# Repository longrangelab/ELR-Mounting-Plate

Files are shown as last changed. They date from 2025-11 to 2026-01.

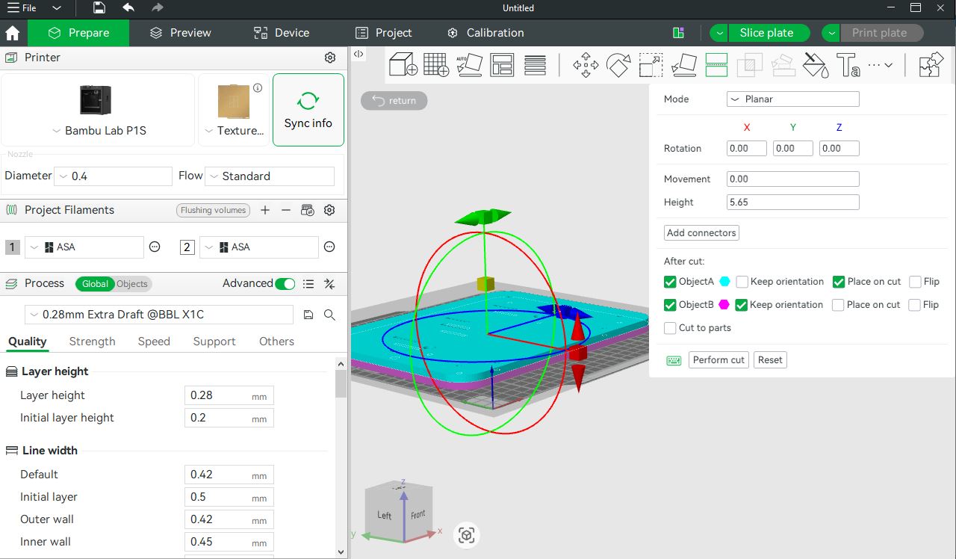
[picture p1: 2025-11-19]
Assets/2nd Cut.JPG

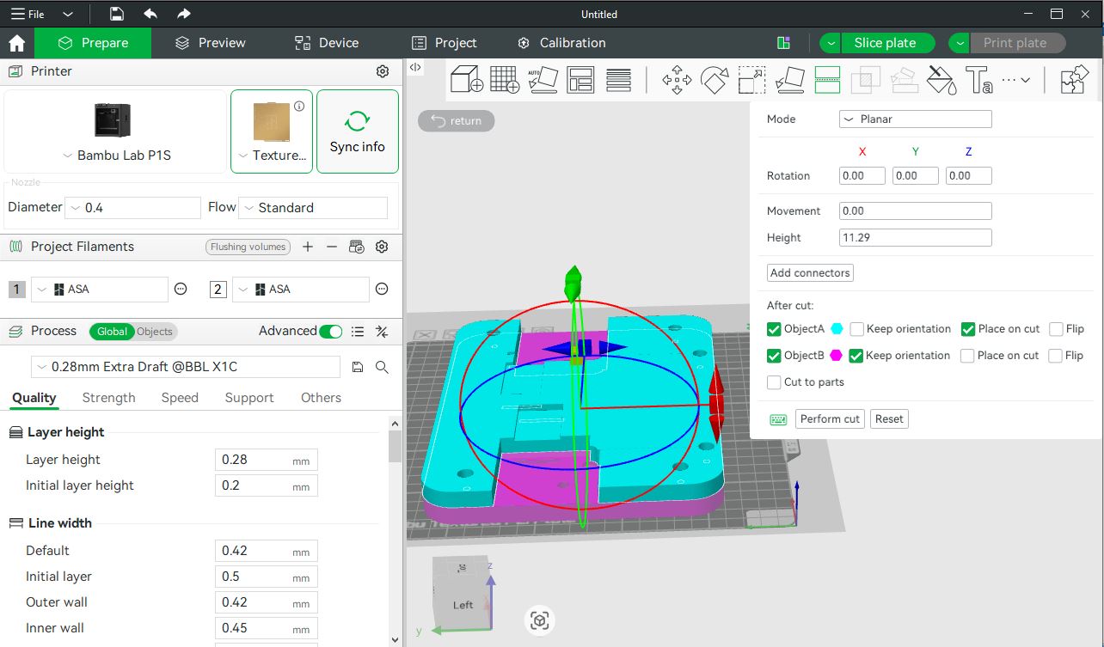
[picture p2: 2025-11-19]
Assets/1st cut.JPG

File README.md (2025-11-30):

# ELR-Mounting-Plate
A rugged, mounting solution for securely attaching electronic hit indicators to steel targets in extreme long-range (ELR) shooting setups. Designed for durability, repeatability, and easy integration with common target systems.
## Open Source Collaboration
The ELR Mounting Plate is fully open source, designed to be shared, modified, and improved by the shooting and maker community. While the current design includes brackets for the Caldwell Flash Bang and MagnetoSpeed T1000, the system is meant to be modular. I encourage contributors to design and submit new brackets for other hit indicators or accessories. By working together, we can expand the versatility of this mounting system and make it a universal solution for ELR shooters everywhere. This is a link to the ONShape document I have been working with:

- https://cad.onshape.com/documents/a04b2efc3583e73eb0067b3f/w/00cdbc6ac526f38cc4cbc277/e/5109c6cf2e963c5b981c8ac2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
Feel free to use it how you see fit :)
IMG_20251123_082742701_HDR
60 fps 0![Back On shape](https://github.com/user-attachments/assets/3fdb3622-1bf8-4e5c-a6eb-2b6bc96cb5c7) 0_00_09_03 Still001

# Current Features/Capabilities
- 🔧 **Hybrid Mounting System**  
  Combines a large Velcro surface with two neodymium magnets for constant pressure against the steel plate.
  
- 🛡️ **Durable Materials**  
  - **ASA plastic**: UV and impact resistant, ideal for outdoor use.  
  - **TPU rubber**: Provides shock absorption and prevents shattering under repeated impacts.  

- 🎯 **Adaptable Design**  
  Compatible with multiple hit indicators:
  - Coriolis Hit Indicator (future project to be completed)
  - Caldwell Flash Bang  
  - MagnetoSpeed T1000  
  - Can be adapted to virtually any hit indicator with future iteration
# To build the ELR Mounting Plate, you will need the following components:

| Qty | Item | Description | Link |
|-----|---|---|---|
| 2 | Neodymium Magnets | 180 lb pull force, heavy-duty magnets for mounting pressure | [Amazon Product Page](https://www.amazon.com/MUTUACTOR-Neodymium-Magnets-Anti-Broken-Equipments/dp/B07JKWCVTX) |
| 4 | M4 Screws (20mm)  | Standard metric screws for securing ASA and TPU layers | — |
| 2 | M4 Screws (25mm)  | Longer screws for reinforced bracket mounting | — |
| 2 | M4 Screws (30mm)  | Extra-long screws for thicker assemblies | — |
| 26  | M4 Washers | Flat washers to distribute load and prevent damage | — |
| 10  | M4 Lock Washers | Locking washers to resist loosening under vibration/impact | — |
| 10  | M4 Nuts | Standard nuts for fastening bolts | — |
| 2 | Velcro Adhesive Dots | 1.5” round industrial-strength adhesive fasteners for mounting | [Amazon Product Page](https://www.amazon.com/pson-Adhesive-Fasteners-Mounting-Industrial/dp/B0F4DZC5RM) |
| 2 | Velcro Pad (6x4”)  | Waterproof double-sided adhesive pad for larger mounting surface | [Amazon Product Page](https://www.amazon.com/Upgrade-Adhesive-Double-Side-Fastener-Waterproof/dp/B07D38TNF9) |
| 1 | Velcro Strap (1/2” wide) | Strap for securing Magneto Speed T1000 hit indicator | [Amazon Product Page](https://www.amazon.com/dp/B0CH8K8VWC) |
| 1 | Support Bar | Tool for safely removing the mounting plate from steel targets | [Amazon Product Page](https://www.amazon.com/dp/B0DYF8F2RN) |
| 1 | TPU 95 Filament | Flexible filament for impact-absorbing core | — |
| 1 | ASA Filament | UV and impact-resistant filament for outer plates | — |

# Step 1: Printing the Plate
- Start by downloading the ELR Mounting PLate STL in the stl folder. The orientation of the plate is pictured below. This requires no support.
- full plate before splitting
- Next, we'll split the plate into 3 different layers: Two layers of ASA on the outside with a layer of TPU sandwiched in the middle. 
- The first cut will be performed horizontally with a depth of approximately 10.37 mm. It will be printed with ASA. 
- 1st cut
- 1st Print ASA

- The next cut will split the remainder of the plate exactly in half, leaving a thickness of about 5.76 mm for the remaining two plates. 
- The opposite outside layer will also be printed with ASA
- 2nd Print ASA

- The third print will be with TPU 95
- 3rd Print TPU95

## Printer Filament Settings

The ELR Mounting Plate uses a **multi-material print** combining ASA for rigidity and TPU95 for impact absorption. Below are the recommended slicer settings for each material:

### ASA (Outer Plates)
| Setting | Value |
|---|---|
| Infill Percentage  | 30% |
| Infill Pattern | Gyroid |
| Wall Passes | 5 |
| Bottom Shell Layers| 5 |
| Top Shell Layers | 5 |

**Notes:**  
- ASA provides UV resistance and high impact strength, making it ideal for outdoor shooting environments.  
- Higher wall count and bottom layers ensure structural rigidity around magnet mounts and screw holes.  
- Gyroid infill balances strength with weight reduction.  

---

### TPU95 (Inner Core)
| Setting | Value |
|---|---|
| Infill Percentage  | 10% |
| Infill Pattern | Gyroid |
| Wall Passes | 3 |
| Bottom Shell Layers| 3 |
| Top Shell Layers | 3 |

**Notes:**  
- TPU95 acts as a shock absorber, preventing cracks and distributing impact forces.  
- Lower infill keeps the core flexible while still providing support.  
- Gyroid infill maintains elasticity and impact resistance.  

---

### Why These Settings?
- **ASA + TPU95 Hybrid:** The rigid ASA shell protects against environmental stress, while the TPU95 core absorbs repeated impacts.  
- **Gyroid Infill:** Provides isotropic strength and flexibility, superior to grid or honeycomb for impact-heavy applications.  
- **Wall Passes & Shell Layers:** Extra walls in ASA prevent shattering, while fewer walls in TPU maintain flexibility.
# Assembly
First, gather all three layers of the mounting plate and align them so that all holes line up. From the steel side view of the plate, place washers in all of the holes, minus the holes intended for the magnets. Place the appropriate size bolt in each of the holes according to the hardware schedule below:
Bolt Layout

Once all of the bolts are in, turn the plate around and place washers, lock washers, and nuts on each of the bolts except for the 4 bolts intended for the hit indicator bracket. 

Next, install the two magnets. Depending on how far you want the magnets to stick out past the plate, you can print TPU spacers that I've included in the STL folder and put this spacer behind the magnet. I would also
recommend using washers on the front side of the plate because this is likely a failure point. The washer will help distribute the large force over a larger footprint. 
Rubber Spacer

After the magnets are installed, stack 3 or 4 washers on each of the 30 mm long bolts to build up a base for the metal joiner bar. Place the joiner bar over the two 30 mm bolts and place a washer, locking washer, and nuts over both bolts. 

# Applying Adhesive Strips
Finally, it's time to apply the adhesive velcro to the back of the plate. Feel free to experiment with different brands of velcro adhesive. If you would like to have access to the ELR Mounting plate's screws, then I would recommend printing out the velcro stencil that I have included in the STL folder. 
Stencil for velcro

Using this stencil will allow you to cut out holes for screws in case you want to take the plate apart, or take the bracket off. 

Drawing holes out
Finished

## Hit indicator brackets

- After all of these steps are completed, you are done building the ELR Mounting Plate. All you have to do now is print the appropriate mounting bracket (Located in the STL folder. Print either the Magneto Speed T1000 or the Caldwell Top and Bottom brackets) depending on which hit indicator you have. You'll then slide the bracket over the 4 remaining bolts and lock the bracket down with locking washers and nuts. 

Fully completed unit

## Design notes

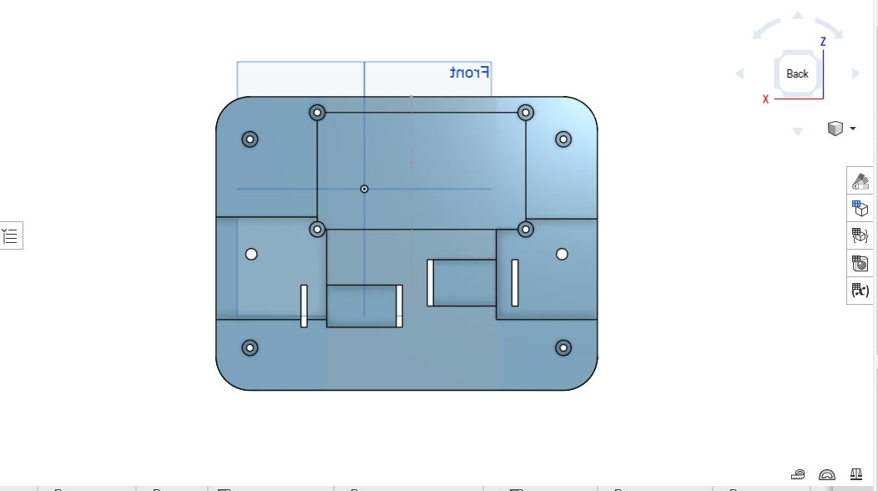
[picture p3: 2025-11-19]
Assets/Back On shape.JPG

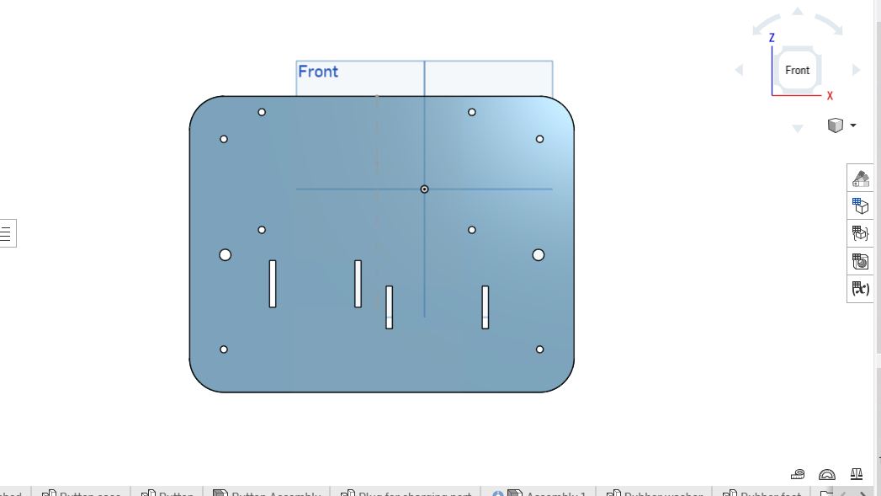
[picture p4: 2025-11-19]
Assets/Front On Shape.JPG

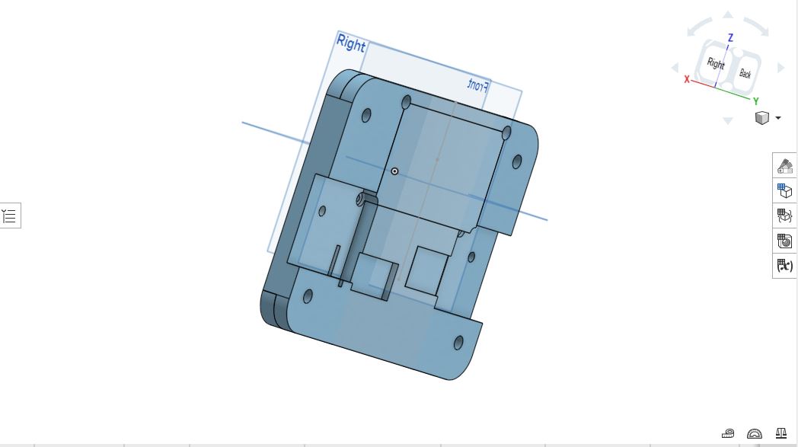
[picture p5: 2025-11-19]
Assets/3d view.JPG

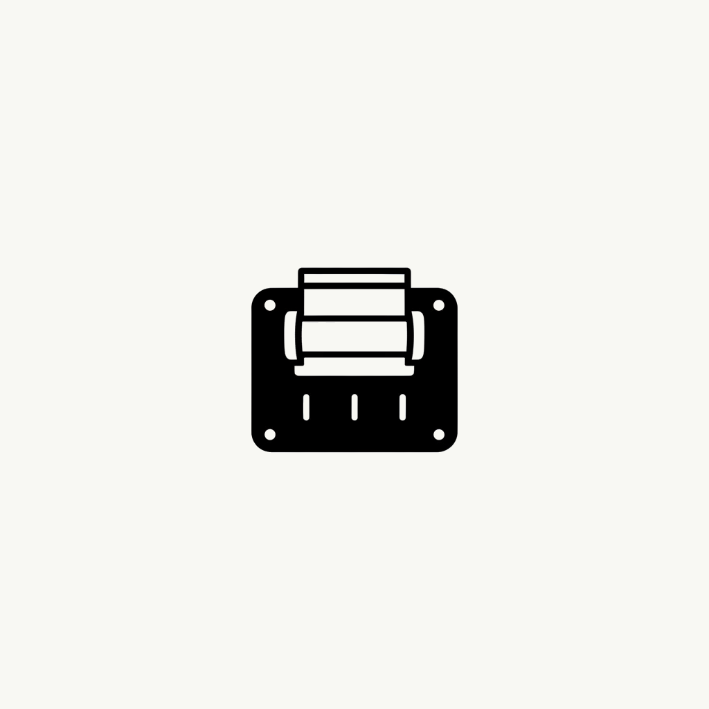
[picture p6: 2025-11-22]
Assets/ELR Mounting plate corrected.png

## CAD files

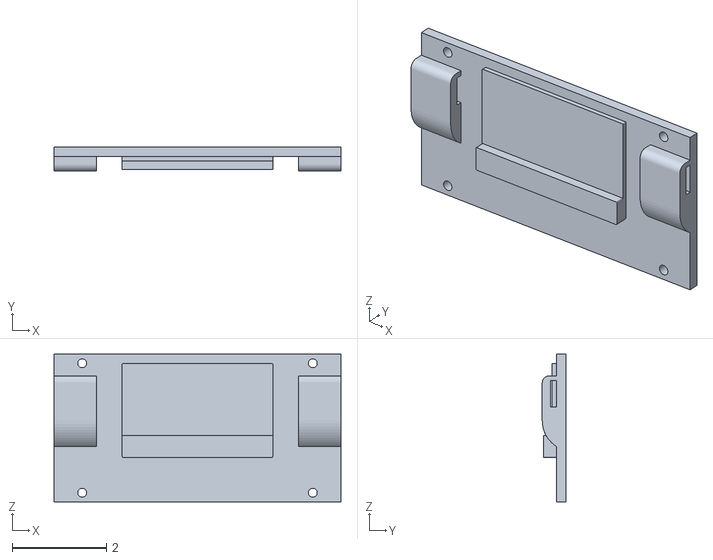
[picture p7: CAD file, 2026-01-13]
STL's/Caldwell Plastic Bracket.stl
6.10 x 0.5 x 3.14

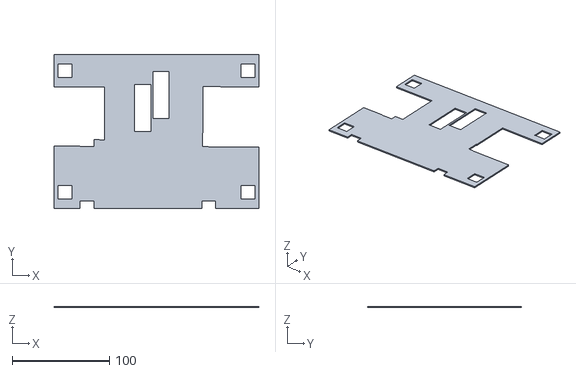
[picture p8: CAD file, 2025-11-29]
STL's/Stencil for Velcro.stl
210.6 x 157.9 x 1.48

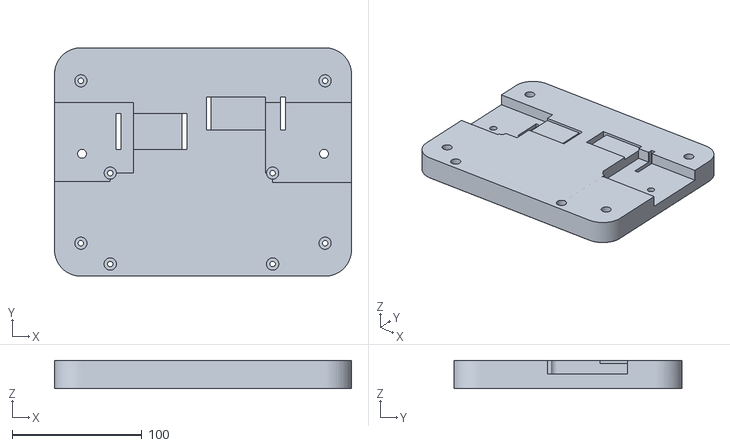
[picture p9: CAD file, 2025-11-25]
STL's/ELR Mounting Plate.stl
228.6 x 175.8 x 21.9

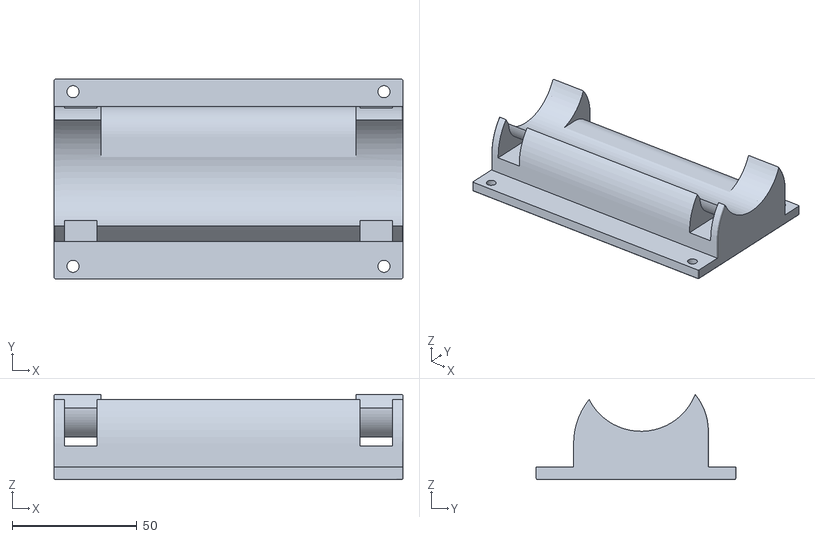
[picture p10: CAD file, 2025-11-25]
STL's/T1000 Bracket.stl
139.7 x 79.9 x 34.1

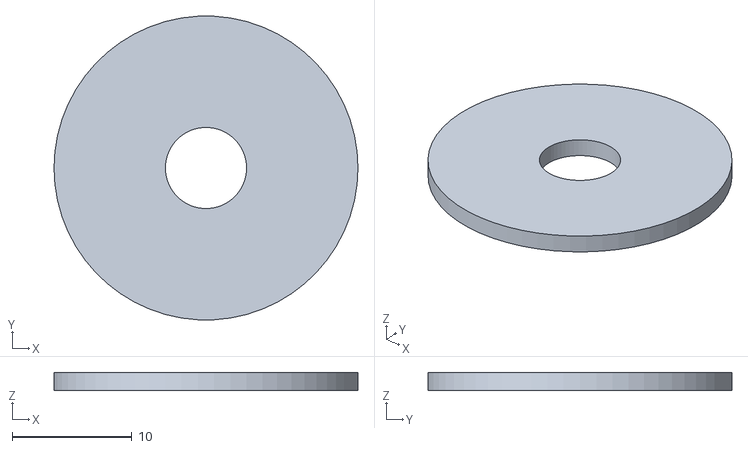
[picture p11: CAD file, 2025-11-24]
STL's/Rubber Washer.stl
25.4 x 25.4 x 1.52

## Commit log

2025-11-19 Pictures/1st Cut
2025-11-19 Add new file '1st Cut' in Assets directory
2025-11-19 Rename caldwell bracket top (1).stl to caldwell bracket - top.stl
    [caldwell bracket - top.stl]
2025-11-23 Update README with features and capabilities
    Added current features and capabilities section to README.
2025-11-23 Add components list for ELR Mounting Plate
    Added a list of components needed to build the ELR Mounting Plate.
2025-11-24 Rename Caldwell Bracket bottom (1).stl to Caldwell Bracket Bottom.stl
    [Caldwell Bracket Bottom.stl]
2025-11-24 Rename caldwell bracket - top.stl to Caldwell Bracket Top.stl
    [Caldwell Bracket Top.stl]
2025-11-24 Rename T1000 Bottom Bracket.stl to T1000 Bracket.stl
    [T1000 Bracket.stl]
2025-11-24 Update README with ONShape link and fix typos
    Added a link to the ONShape document for the ELR Mounting Plate and corrected minor typos in the README.
2025-11-30 Add Top Shell Layers to material specifications
